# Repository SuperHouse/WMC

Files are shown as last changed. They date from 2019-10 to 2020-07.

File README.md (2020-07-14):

Wheelchair Motor Controller
===========================

Motion controller for an electric wheelchair using 24V DC motors, such
as a Permobil F5.

Controls two wheelchair motors using a RoboClaw motor driver. It also
has outputs for a solenoid braking system, and a CAN bus interface to
communicate with other modules on the chair.

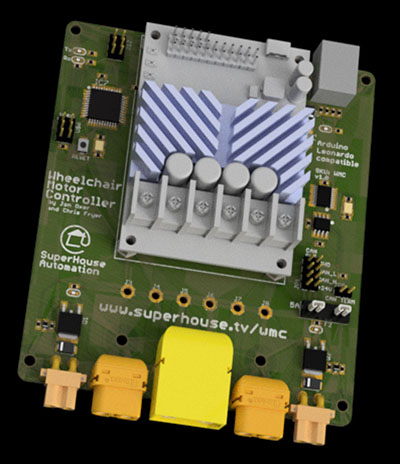
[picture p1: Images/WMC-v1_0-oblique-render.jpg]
Wheelchair Motor Controller


Features:

 * Takes power from the chair battery.
 * Mounting location for RoboClaw motor driver.
 * Communicates with RoboClaw using serial commands.
 * MOSFETs to release mechanical brakes.
 * CAN bus.

More information is available at:

  https://www.superhouse.tv/wmc

Hardware
--------
The "Hardware" directory contains the PCB design as an EAGLE project.
EAGLE PCB design software is available from Autodesk free for
non-commercial use.

Firmware
--------
The "Firmware" directory contains example firmware as an Arduino
project.

Credits
-------
 * Jonathan Oxer <jon@oxer.com.au>
 * Chris Fryer <chris.fryer78@gmail.com>

License
-------
Copyright 2019-2020 SuperHouse Automation Pty Ltd  www.superhouse.tv  

The hardware portion of this project is licensed under the TAPR Open
Hardware License (www.tapr.org/OHL). The "license" folder within this
repository contains a copy of this license in plain text format.

The software portion of this project is licensed under the Simplified
BSD License. The "licence" folder within this project contains a
copy of this license in plain text format.

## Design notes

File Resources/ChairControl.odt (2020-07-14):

Chair Controller

Modular open source electric wheelchair controller.

Different methods of control to both drive the chair and to operate an arbitrary number of and variety of actuator.

Using a button and joystick to navigate a menu to control chair functions, or having a single button for each function when user is unwilling or unable to use a menu.

The chair must be able to integrate with other accessible technologies. Such as operating as a HID device, eg. a bluetooth mouse or keyboard and connecting to an environmental control system.

EWC autopilot.

Setting up the wheelchair should be as simple and accessible as possible – not needing any special equipment to do so – while also giving advanced users advanced options including a well documented API. I’m thinking a web based interface due to the ubiquity of web browsers.

It needs to be easy to add custom modules. All hardware and software on the chair should be “off the shelf”, such as the use of CAN throughout and Arduino compatible microcontrollers. I wish it to be possible to use

Chair needs

Normal proportional joystick.

Mini Joystick.

On / Off switch.

Button.

Contact button.

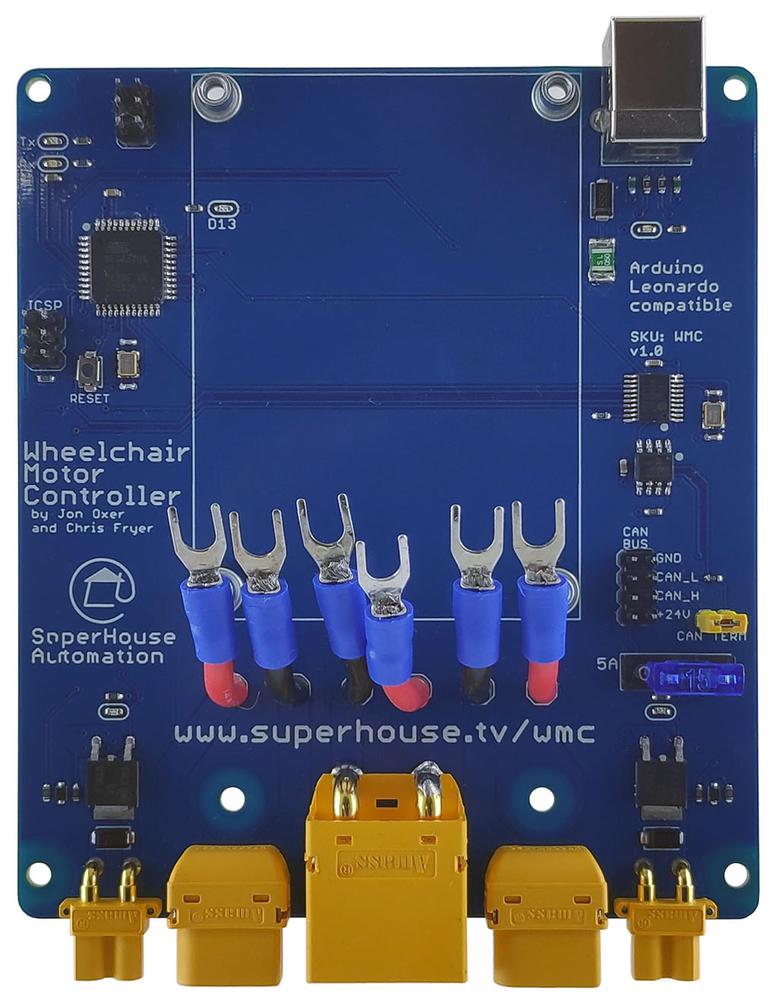
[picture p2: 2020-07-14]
Images/WMC-v1_0-top.jpg

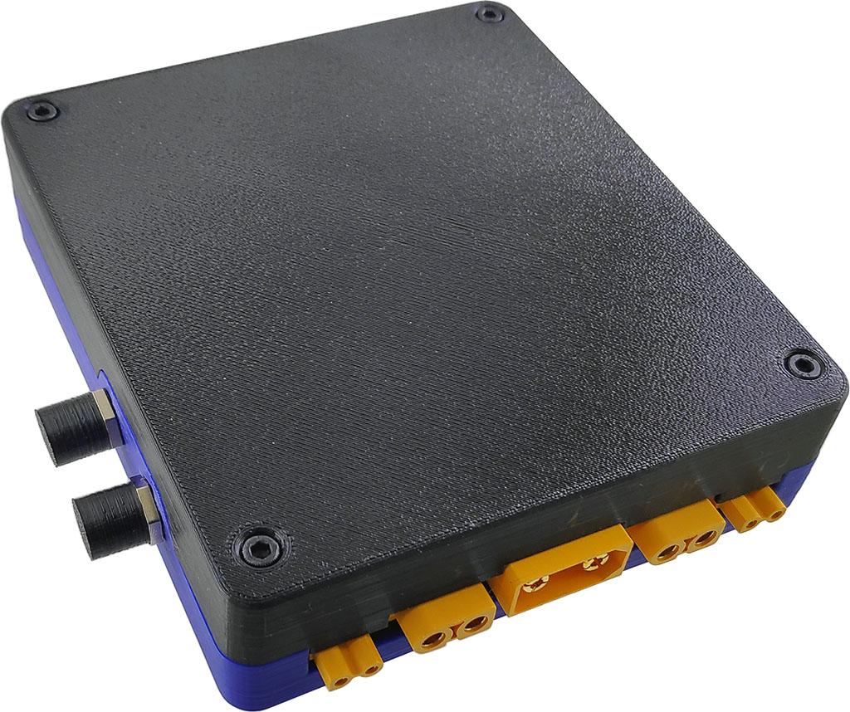
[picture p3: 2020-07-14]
Images/WMC-v1_0-case.jpg

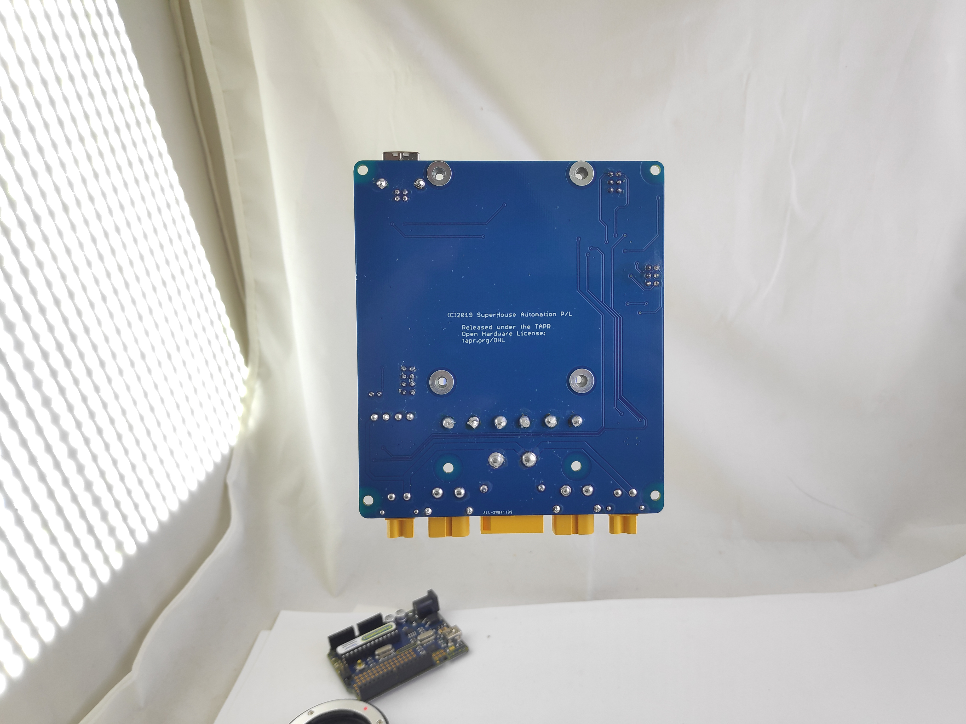
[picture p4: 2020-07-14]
Images/2019-10-31 21.18.55.jpg

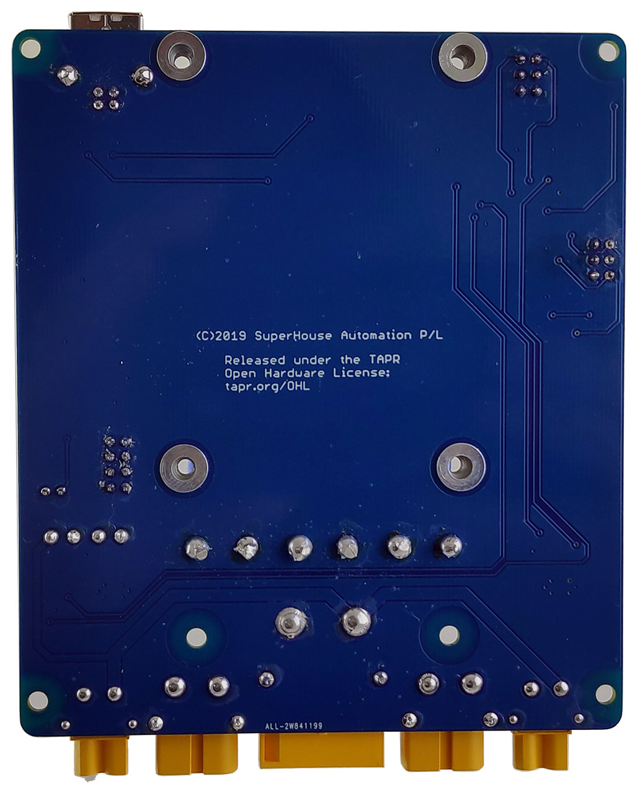
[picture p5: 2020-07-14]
Images/WMC-v1_0-bottom.jpg

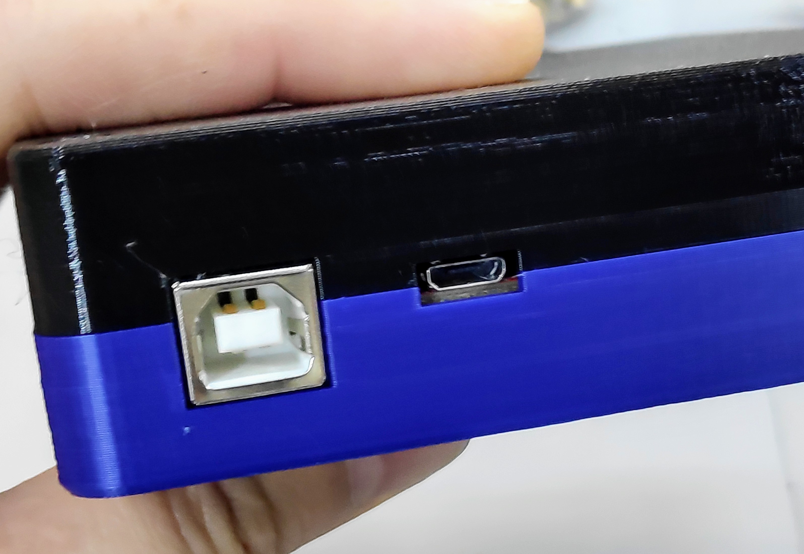
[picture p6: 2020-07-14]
Images/2019-11-03 09.05.40.jpg

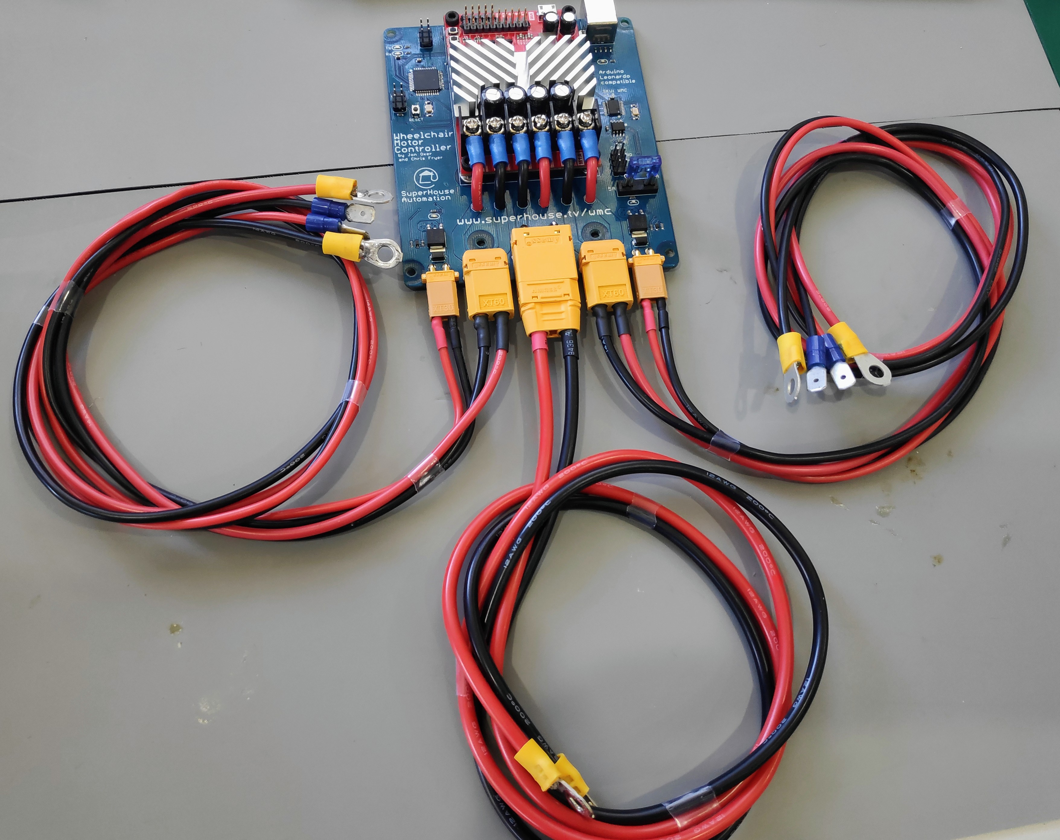
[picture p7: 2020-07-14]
Images/2019-10-29 14.47.06.jpg

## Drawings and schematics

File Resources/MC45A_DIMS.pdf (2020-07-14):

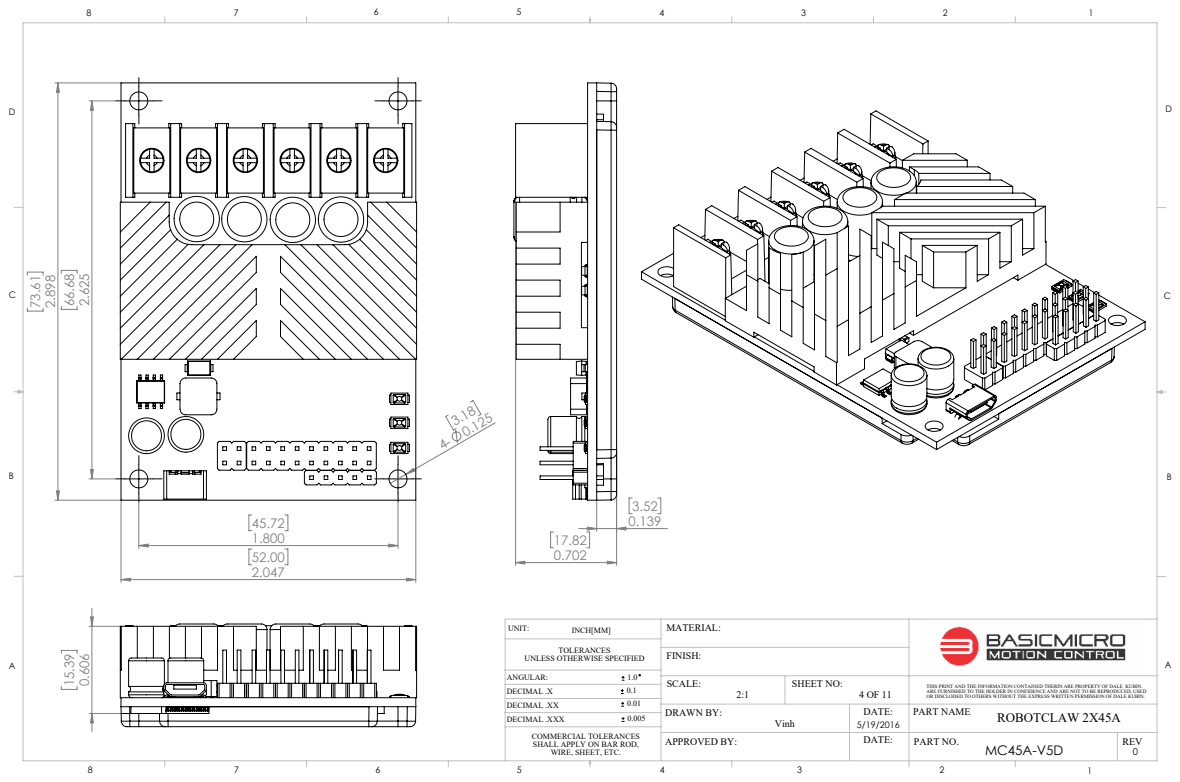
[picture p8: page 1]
PART NO.; REV; DRAWN BY:; APPROVED BY:; SCALE:; SHEET NO:; ROBOTCLAW 2X45A Vinh

UNLESS OTHERWISE SPECIFIED
ANGULAR:
DECIMAL .X
DECIMAL .XX
DECIMAL .XXX
COMMERCIAL TOLERANCES
SHALL APPLY ON BAR ROD,
WIRE, SHEET, ETC.

THIS PRINT AND THE INFORMATION CONTAINED THERIN ARE PROPERTY OF DALE KUBIN.
ARE FURNISHED TO THE HOLDER IN CONFIDENCE AND ARE NOT TO BE REPRODUCED, USED
OR DISCLODED TO OTHERS WITHOUT THE EXPRESS WRITTEN PERMISSION OF DALE KUBIN.
PART NAME

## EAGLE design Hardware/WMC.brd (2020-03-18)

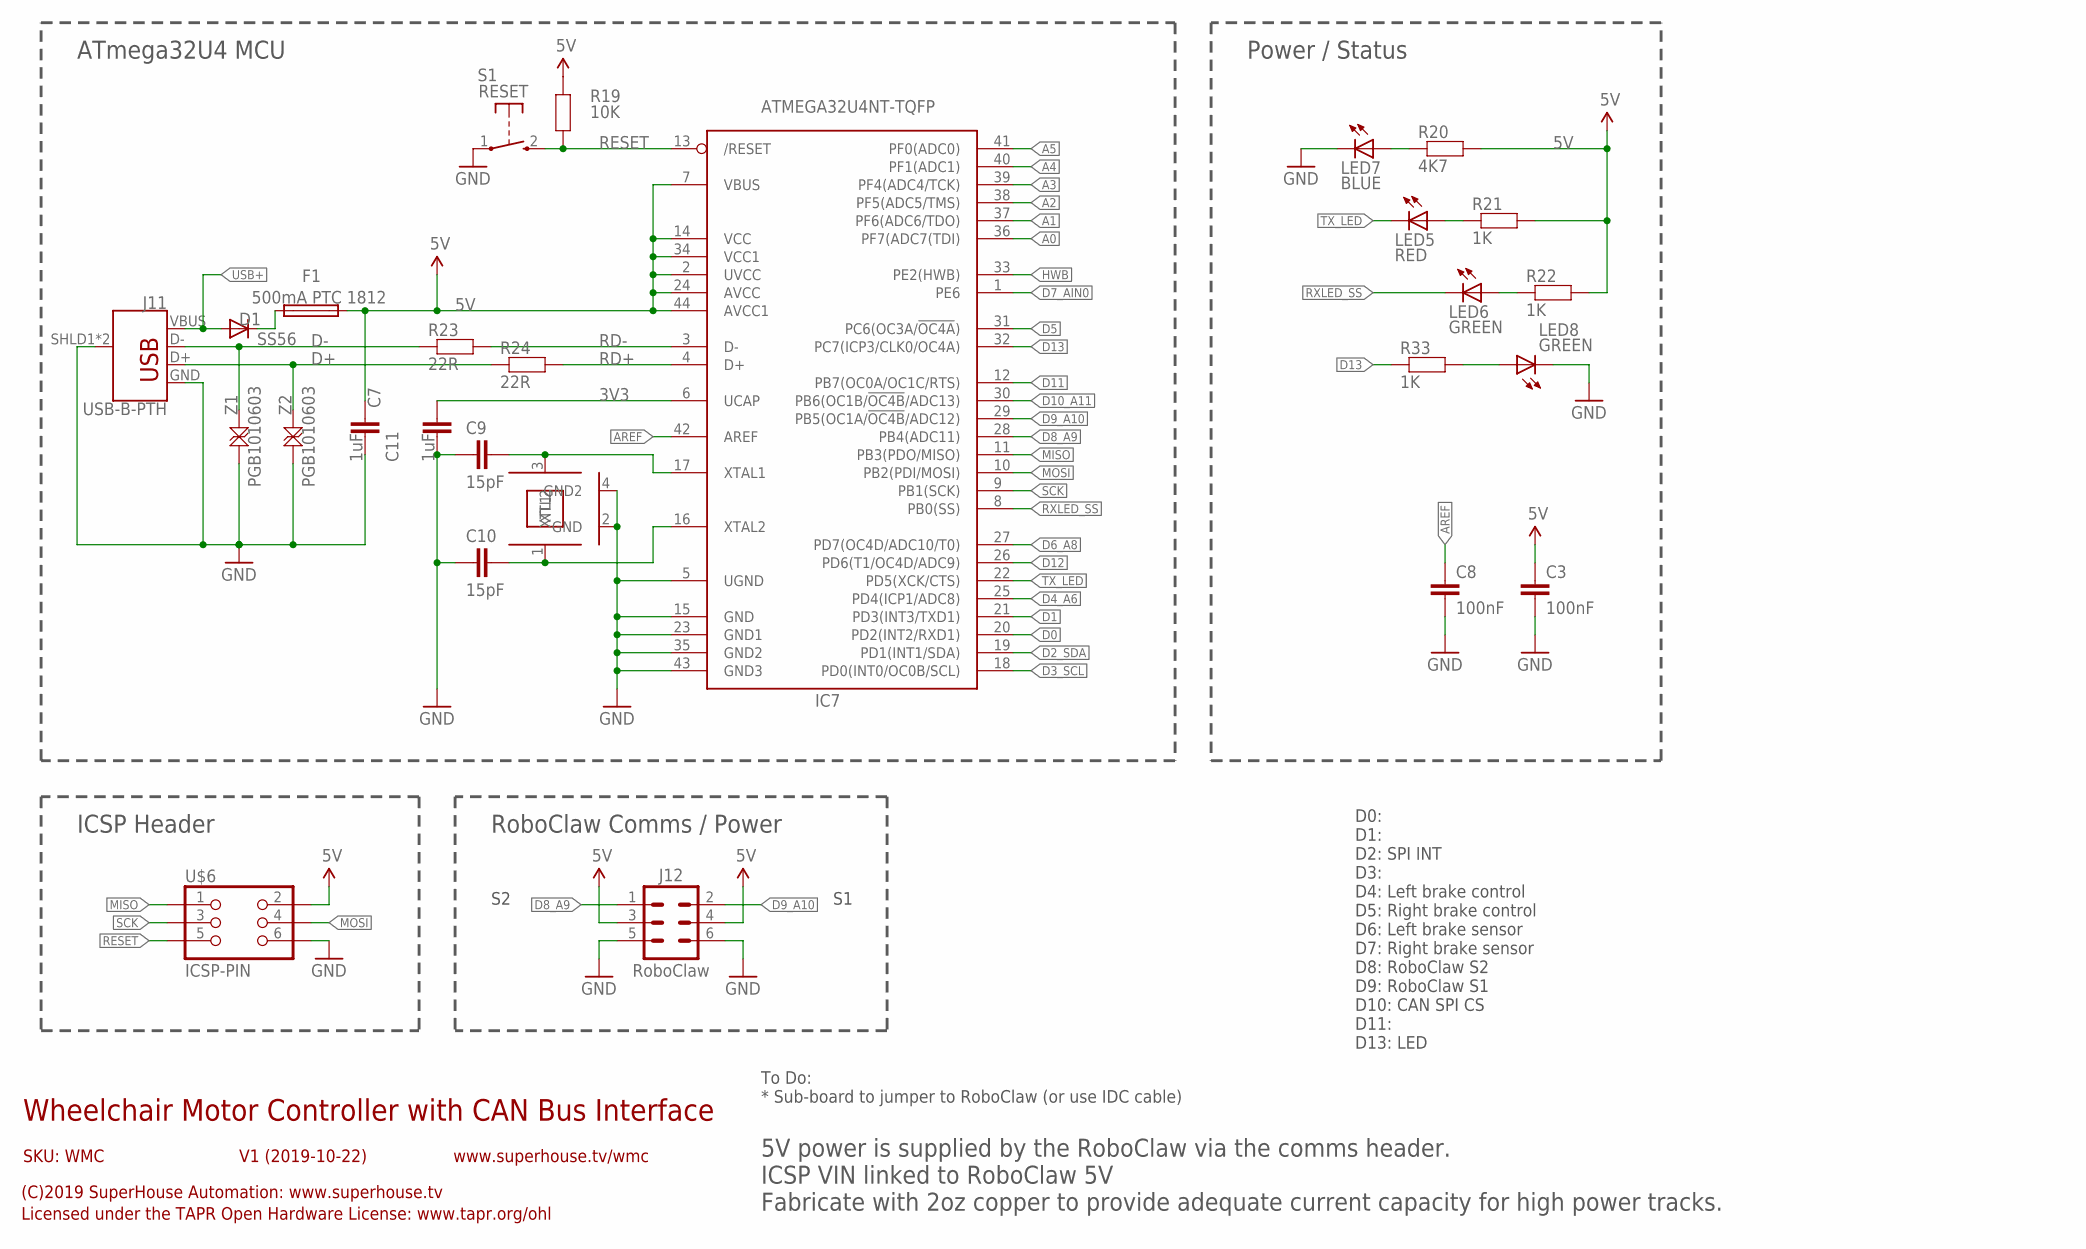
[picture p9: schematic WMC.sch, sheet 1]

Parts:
C3, C8: 100nF; C0603
C7, C11: 1uF; C0603
C9, C10: 15pF; C0603
D1: SS56; SMA-DIODE
F1: 500mA PTC 1812; 1812
IC7: ATMEGA32U4NT-TQFP; TQFP44
J11: USB-B-PTH
J12: RoboClaw; 2X03-P
LED5: RED; LED-0603
LED6, LED8: GREEN; LED-0603
LED7: BLUE; LED-0603
R19: 10K; R0603
R20: 4K7; R0603
R21, R22, R33: 1K; R0603
R23, R24: 22R; R0603
S1: RESET; TACTILE_SMT_3X4X2
U$6: ICSP-PIN; 2X03-ICSP
XTL2: 16MHz; CRYSTAL-SMD-3X2
Z1, Z2: PGB1010603; TVS0603

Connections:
3V3: C11.2, IC7.6 (UCAP)
5V: C3.1, C7.1, F1.2, IC7.2 (UVCC), IC7.7 (VBUS), IC7.14 (VCC), IC7.24 (AVCC), IC7.34 (VCC1), IC7.44 (AVCC1), J12.3, J12.4, R19.2, R20.2, R21.2, R22.2, U$6.2; also elsewhere on the board
A0: IC7.36 (PF7(ADC7(TDI))
A1: IC7.37 (PF6(ADC6/TDO))
A2: IC7.38 (PF5(ADC5/TMS))
A3: IC7.39 (PF4(ADC4/TCK))
A4: IC7.40 (PF1(ADC1))
A5: IC7.41 (PF0(ADC0))
AREF: C8.1, IC7.42 (AREF)
D0: IC7.20 (PD2(INT2/RXD1))
D1: IC7.21 (PD3(INT3/TXD1))
D2_SDA: IC7.19 (PD1(INT1/SDA)); also elsewhere on the board
D3_SCL: IC7.18 (PD0(INT0/OC0B/SCL))
D4_A6: IC7.25 (PD4(ICP1/ADC8)); also elsewhere on the board
D5: IC7.31 (PC6(OC3A/!OC4A!)); also elsewhere on the board
D6_A8: IC7.27 (PD7(OC4D/ADC10/T0)); also elsewhere on the board
D7_AIN0: IC7.1 (PE6); also elsewhere on the board
D8_A9: IC7.28 (PB4(ADC11)), J12.1
D9_A10: IC7.29 (PB5(OC1A/!OC4B!/ADC12)), J12.2
D10_A11: IC7.30 (PB6(OC1B/!OC4B!/ADC13)); also elsewhere on the board
D11: IC7.12 (PB7(OC0A/OC1C/RTS))
D12: IC7.26 (PD6(T1/OC4D/ADC9))
D13: IC7.32 (PC7(ICP3/CLK0/OC4A)), R33.1
D+: J11.D+, R24.1, Z2.2
D-: J11.D-, R23.1, Z1.2
GND: C3.2, C7.2, C8.2, C9.1, C10.1, C11.1, IC7.5 (UGND), IC7.15 (GND), IC7.23 (GND1), IC7.35 (GND2), IC7.43 (GND3), J11.GND, J11.SHLD1 (SHIELD), J11.SHLD2 (SHIELD), J12.5, J12.6, LED7.C, LED8.C, S1.1, U$6.6, XTL2.2 (GND), XTL2.4 (GND2), Z1.1, Z2.1; also elsewhere on the board
HWB: IC7.33 (PE2(HWB))
MISO: IC7.11 (PB3(PDO/MISO)), U$6.1; also elsewhere on the board
MOSI: IC7.10 (PB2(PDI/MOSI)), U$6.4; also elsewhere on the board
unnamed: C9.2, IC7.17 (XTAL1), XTL2.3 (XTL2)
unnamed: C10.2, IC7.16 (XTAL2), XTL2.1 (XTL1)
unnamed: LED7.A, R20.1
unnamed: LED5.A, R21.1
unnamed: LED6.A, R22.1
unnamed: D1.C, F1.1
unnamed: LED8.A, R33.2
RD+: IC7.4 (D+), R24.2
RD-: IC7.3 (D-), R23.2
RESET: IC7.13 (/RESET), R19.1, S1.2 (S), U$6.5
RXLED_SS: IC7.8 (PB0(SS)), LED6.C
SCK: IC7.9 (PB1(SCK)), U$6.3; also elsewhere on the board
TX_LED: IC7.22 (PD5(XCK/CTS)), LED5.C
USB+: D1.A, J11.VBUS

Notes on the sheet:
Wheelchair Motor Controller with CAN Bus Interface
V1 (2019-10-22)
SKU: WMC
(C)2019 SuperHouse Automation: www.superhouse.tv
Licensed under the TAPR Open Hardware License: www.tapr.org/ohl
www.superhouse.tv/wmc
To Do: * Sub-board to jumper to RoboClaw (or use IDC cable)
ATmega32U4 MCU
Power / Status
ICSP Header
RoboClaw Comms / Power
5V power is supplied by the RoboClaw via the comms header. ICSP VIN linked to RoboClaw 5V Fabricate with 2oz copper to provide adequate current capacity for high power tracks.
D0: D1: D2: SPI INT D3: D4: Left brake control D5: Right brake control D6: Left brake sensor D7: Right brake sensor D8: RoboClaw S2 D9: RoboClaw S1 D10: CAN SPI CS D11: D13: LED

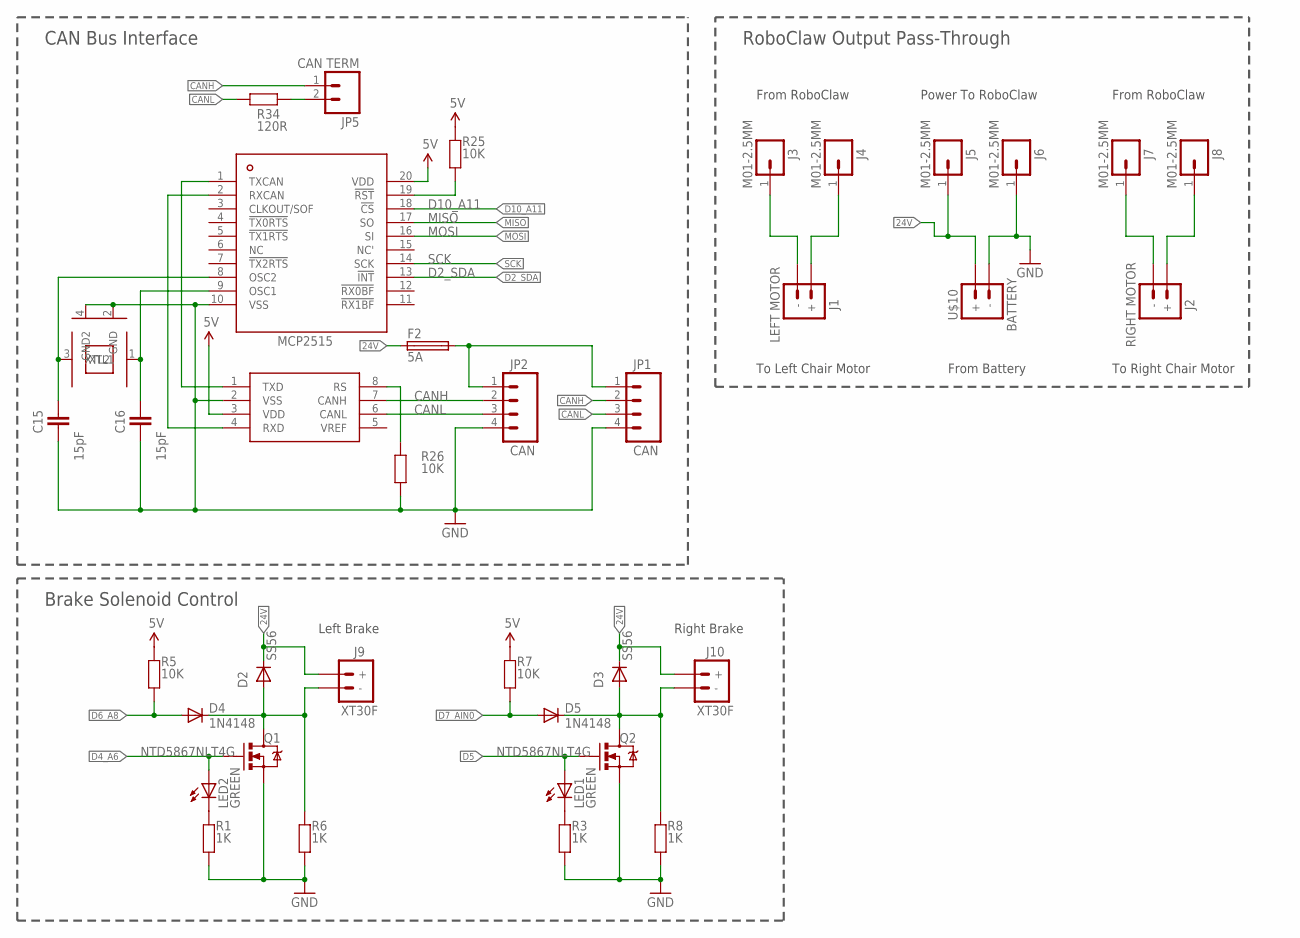
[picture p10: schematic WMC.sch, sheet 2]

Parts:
C15, C16: 15pF; C0603
D2, D3: SS56; SMA-DIODE
D4, D5: 1N4148; SOD-323
F2: 5A; MCCQ-122
IC5: MCP2551; SO08
IC6: MCP2515; TSSOP20
J1: LEFT MOTOR; XT60PW-F
J2: RIGHT MOTOR; XT60PW-F
J3, J4, J5, J6, J7, J8: M01-2.5MM; 1X01-2.5MM
J9, J10: XT30F; XT30PW-F
JP1, JP2: CAN; 1X04-P
JP5: CAN TERM; 1X02-P
LED1, LED2: GREEN; LED-0603
Q1, Q2: NTD5867NLT4G; DPACK
R1, R3, R6, R8: 1K; R0603
R5, R7, R25, R26: 10K; R0603
R34: 120R; R0603
U$10: BATTERY; XT90PW-M
XTL4: 16MHz; CRYSTAL-SMD-3X2

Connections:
5V: IC5.3 (VDD), IC6.20 (VDD), R5.2, R7.2, R25.2; also elsewhere on the board
24V: D2.C, D3.C, F2.1, F2.2 (1), J5.1, J9.+, J10.+, U$10.+
CANH: IC5.7 (CANH), JP1.2, JP2.2, JP5.1
CANL: IC5.6 (CANL), JP1.3, JP2.3, R34.1
D2_SDA: IC6.13 (!INT); also elsewhere on the board
D4_A6: LED2.A, Q1.1 (G); also elsewhere on the board
D5: LED1.A, Q2.1 (G); also elsewhere on the board
D6_A8: D4.2 (A), R5.1; also elsewhere on the board
D7_AIN0: D5.2 (A), R7.1; also elsewhere on the board
D10_A11: IC6.18 (!CS); also elsewhere on the board
GND: C15.1, C16.1, IC5.2 (VSS), IC6.10 (VSS), J6.1, JP1.4, JP2.4, Q1.3 (S), Q2.3 (S), R1.1, R3.1, R6.1, R8.1, R26.1, U$10.-, XTL4.2 (GND), XTL4.4 (GND2); also elsewhere on the board
LEFT_BRAKE: D2.A, D4.1 (C), J9.-, Q1.2 (D), R6.2
MISO: IC6.17 (SO); also elsewhere on the board
MOSI: IC6.16 (SI); also elsewhere on the board
unnamed: LED2.C, R1.2
unnamed: F2.3 (2), F2.4 (2), JP1.1, JP2.1
unnamed: J1.+, J4.1
unnamed: LED1.C, R3.2
unnamed: J1.-, J3.1
unnamed: J2.-, J7.1
unnamed: J2.+, J8.1
unnamed: IC6.19 (!RST), R25.1
unnamed: IC5.1 (TXD), IC6.1 (TXCAN)
unnamed: IC5.4 (RXD), IC6.2 (RXCAN)
unnamed: IC5.8 (RS), R26.2
unnamed: C15.2, IC6.8 (OSC2), XTL4.3 (XTL2)
unnamed: C16.2, IC6.9 (OSC1), XTL4.1 (XTL1)
unnamed: JP5.2, R34.2
RIGHT_BRAKE: D3.A, D5.1 (C), J10.-, Q2.2 (D), R8.2
SCK: IC6.14 (SCK); also elsewhere on the board

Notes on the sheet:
RoboClaw Output Pass-Through
CAN Bus Interface
Brake Solenoid Control
Left Brake
Right Brake
From RoboClaw
From Battery
To Right Chair Motor
To Left Chair Motor
Power To RoboClaw

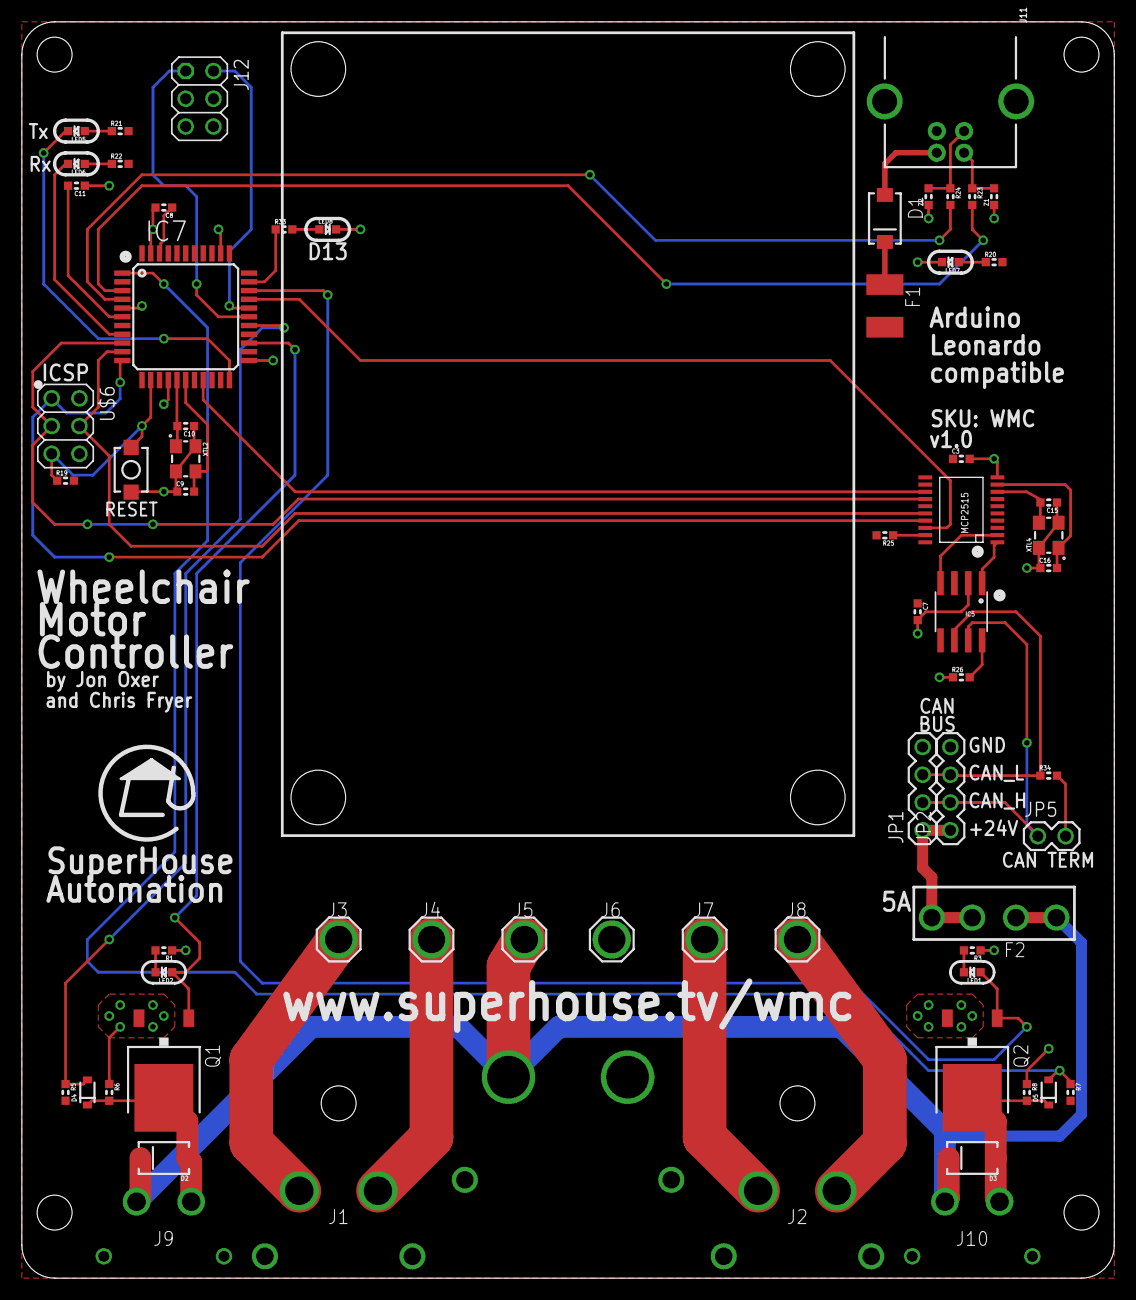
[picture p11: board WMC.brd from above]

Board: 2 copper layers, 100.0 x 115.0 mm, 64 parts (0 on the bottom side), 50 nets.

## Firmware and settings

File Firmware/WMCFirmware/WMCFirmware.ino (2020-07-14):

/**
   Receives messages via CAN bus and controls a RoboClaw motor driver module.

   Intended for testing of wheelchair control using a RoboClaw motor controller,
   with commands received over CAN bus from a Chair Breakout Mini attached to
   a wheelchair joystick.

   CAN message format is currently very simplistic, and doesn't adhere to CANopen
   or any other sensible convention. It uses packet IDs to designate the axis:

    Packet ID 0x12 = X axis
    Packet ID 0x13 = Y axis

   The message value signifies the position, from 0 to 127, with 64 as the mid
   point. So a centered joystick would have:

     Packet ID: 0x12. Value: 64
     Packet ID: 0x13. Value: 64

    Joystick full forward would have:

     Packet ID: 0x12. Value: 64
     Packet ID: 0x13. Value: 127

   By Chris Fryer (chris.fryer78@gmail.com) and Jonathan Oxer (jon@oxer.com.au)
   www.superhouse.tv

   To do:
   - Activate brakes when speed reaches 0. This needs to be checked with the RoboClaw,
   because the chair may take a while to stop after it has been set to 0 speed.
*/


// Configuration should be done in the included file:
#include "config.h"

#include <CAN.h>             // CAN bus communication: https://github.com/sandeepmistry/arduino-CAN (available in library manager)
#include <SoftwareSerial.h>  // Required for RoboClaw serial connection
#include "RoboClaw.h"        // Library from BasicMicro

// Serial link to RoboClaw
SoftwareSerial serial(RC_S1, RC_S2);
RoboClaw roboclaw(&serial, 10000);

String SerialBuffer = ""; // Buffer for incoming serial messages from console

// The "...InputValue" variables are taken from inputs and mixed or used directly
int XInputValue = MID_OUTPUT_VALUE; // Start at the mid-point
int YInputValue = MID_OUTPUT_VALUE; // Start at the mid-point

// The "...MotorSetpoint" variables are the target speed we want to reach
double LeftMotorSetpoint  = MID_OUTPUT_VALUE; // Start at the mid-point
double RightMotorSetpoint = MID_OUTPUT_VALUE; // Start at the mid-point

// The "...MotorCurrentValue" variables are directly used to drive the motors
double LeftMotorCurrentValue  = MID_OUTPUT_VALUE;
double RightMotorCurrentValue = MID_OUTPUT_VALUE;

// Recalculate the motor speed based on current and target
long last_calculation_time = 0;
unsigned int motor_output_calculation_interval = 100; // How often to update the motor speed
int speed_output_acceleration_increment = 2; // How big the jump should be per interval
int speed_output_deceleration_increment = 5; // How big the jump should be per interval

// Check whether we need to apply the brakes
long last_brake_check_time = 0;
unsigned int brake_check_interval = 500;

// Serial port reports
long last_serial_report_time = 0;
unsigned int serial_report_interval = 200;

// CAN bus reports
long last_can_report_time = 0;
unsigned int can_report_interval = 500;

char can_msg[8];                   // Buffer for outgoing CAN messages
char incoming_message_buffer[12];  // Buffer for incoming CAN messages

// Check temperature of RoboClaw motor driver
float roboclaw_temperature              = 0.0;
long last_temperature_check_time        = 0;
unsigned int temperature_check_interval = 1000;
float roboclaw_voltage                  = 0.0;
float roboclaw_left_current             = 0.0;
float roboclaw_right_current            = 0.0;

/*
   Setup
*/
void setup() {
  Serial.begin(115200);     // Console
  //while (!Serial) {
  //  ; // wait for serial port to connect. Needed for native USB port only
  //}

  Serial.println("RoboClaw CAN bus interface v1.2");

  Serial.print("Opening serial comms to RoboClaw: ");
  roboclaw.begin(38400);  // RoboClaw packet serial connection
  char version[32];
  if (roboclaw.ReadVersion(ADDRESS, version)) {
    Serial.print(version);
    Serial.println(" done");
  } else {
    Serial.println(" FAILED");
  }

  Serial.print("Setting brake control outputs and sensors: ");
  pinMode(LEFT_BRAKE_CONTROL_PIN,  OUTPUT);
  pinMode(RIGHT_BRAKE_CONTROL_PIN, OUTPUT);
  pinMode(LEFT_BRAKE_SENSOR_PIN,   INPUT);
  pinMode(RIGHT_BRAKE_SENSOR_PIN,  INPUT);
  digitalWrite(LEFT_BRAKE_CONTROL_PIN,  LOW);
  digitalWrite(RIGHT_BRAKE_CONTROL_PIN, LOW);
  Serial.println("done");

  //Set PID Coefficients
  roboclaw.SetM1VelocityPID(ADDRESS, KD, KP, KI, QPPS); // Right motor
  roboclaw.SetM2VelocityPID(ADDRESS, KD, KP, KI, QPPS); // Left motor

  Serial.println("Starting CAN Receiver");
  // start the CAN bus at 500 kbps
  if (!CAN.begin(500E3)) {
    Serial.println("Starting CAN failed!");
    //while (1);
  } else {
    Serial.println("Started CAN OK");
  }

  // register the receive callback
  CAN.onReceive(onReceive);

  delay(100);
}

/**
   Loop
*/
void loop() {
  long current_time = millis(); // Used by various timed events in the loop

  /**
     Motor speed updates can be managed in this sketch, or they can be
     delegated to the RoboClaw if the PID values are set correctly. The
     first option below applies acceleration control within the sketch,
     while the second attempts to drive the motors immediately to their
     target speed and relies on the RoboClaw to take care of smoothing.
  */
  // OPTION 1: Manage acceleration within the sketch.

  // Update the desired motor setting periodically
  if (current_time > (last_calculation_time + motor_output_calculation_interval))
  {
    // WARNING: the calculations below don't yet account for overshoot, so
    // the increment could take it past the target

    /* Motor moving forwards (Speed greater than 64) */
    if (LeftMotorCurrentValue >= 64) // We're moving forwards
    {      
      if (LeftMotorCurrentValue < LeftMotorSetpoint) // Accelerating forwards
      {
        if((LeftMotorSetpoint - LeftMotorCurrentValue) < speed_output_deceleration_increment) // If we're closer than the increment
        {
          LeftMotorCurrentValue = LeftMotorSetpoint;
        } else {
          LeftMotorCurrentValue += speed_output_acceleration_increment;
        }
      }
      if (LeftMotorCurrentValue > LeftMotorSetpoint) // Decelerating forwards
      {
        if((LeftMotorCurrentValue - LeftMotorSetpoint) < speed_output_deceleration_increment) // If we're closer than the increment
        {
          LeftMotorCurrentValue = LeftMotorSetpoint;
        } else {
          LeftMotorCurrentValue -= speed_output_deceleration_increment;
        }
      }
    }

    if (RightMotorCurrentValue >= 64) // We're moving forwards
    {      
      if (RightMotorCurrentValue < RightMotorSetpoint) // Accelerating forwards
      {
        if((RightMotorSetpoint - RightMotorCurrentValue) < speed_output_deceleration_increment) // If we're closer than the increment
        {
          RightMotorCurrentValue = RightMotorSetpoint;
        } else {
          RightMotorCurrentValue += speed_output_acceleration_increment;
        }
      }
      if (RightMotorCurrentValue > RightMotorSetpoint) // Decelerating forwards
      {
        if((RightMotorCurrentValue - RightMotorSetpoint) < speed_output_deceleration_increment) // If we're closer than the increment
        {
          RightMotorCurrentValue = RightMotorSetpoint;
        } else {
          RightMotorCurrentValue -= speed_output_deceleration_increment;
        }
      }
    }

    /* Motor moving backwards (Speed less than 64) */
    if (LeftMotorCurrentValue < 64) // We're moving backwards
    {      
      if (LeftMotorCurrentValue > LeftMotorSetpoint) // Accelerating backwards
      {
        if((LeftMotorCurrentValue - LeftMotorSetpoint) < speed_output_deceleration_increment) // If we're closer than the increment
        {
          LeftMotorCurrentValue = LeftMotorSetpoint;
        } else {
          LeftMotorCurrentValue -= speed_output_acceleration_increment;
        }
      }
      if (LeftMotorCurrentValue < LeftMotorSetpoint) // Decelerating backwards
      {
        if((LeftMotorSetpoint - LeftMotorCurrentValue) < speed_output_deceleration_increment) // If we're closer than the increment
        {
          LeftMotorCurrentValue = LeftMotorSetpoint;
        } else {
          LeftMotorCurrentValue += speed_output_deceleration_increment;
        }
      }
    }

    if (RightMotorCurrentValue < 64) // We're moving backwards
    {      
      if (RightMotorCurrentValue > RightMotorSetpoint) // Accelerating backwards
      {
        if((RightMotorCurrentValue - RightMotorSetpoint) < speed_output_deceleration_increment) // If we're closer than the increment
        {
          RightMotorCurrentValue = RightMotorSetpoint;
        } else {
          RightMotorCurrentValue -= speed_output_acceleration_increment;
        }
      }
      if (RightMotorCurrentValue < RightMotorSetpoint) // Decelerating backwards
      {
        if((RightMotorSetpoint - RightMotorCurrentValue) < speed_output_deceleration_increment) // If we're closer than the increment
        {
          RightMotorCurrentValue = RightMotorSetpoint;
        } else {
          RightMotorCurrentValue += speed_output_deceleration_increment;
        }
      }
    }

    last_calculation_time = current_time;
  }


  // Option 2: Allow RoboClaw to control motor response.
  //LeftMotorCurrentValue = LeftMotorSetpoint;
  //RightMotorCurrentValue = RightMotorSetpoint;


  // See if either wheel is stationary, and apply the brake if it is
  if (current_time > (last_brake_check_time + brake_check_interval))
  {
    //long LeftMotorSpeed  = roboclaw.ReadSpeedM2(ADDRESS);
    //if(LeftMotorSpeed == 0)
    if (LeftMotorCurrentValue >= (MID_OUTPUT_VALUE - DEAD_SPOT_WIDTH) && LeftMotorCurrentValue <= (MID_OUTPUT_VALUE + DEAD_SPOT_WIDTH))
    {
      digitalWrite(LEFT_BRAKE_CONTROL_PIN, LOW);
      //Serial.println("Left brake applied");
    }
    //long RightMotorSpeed = roboclaw.ReadSpeedM1(ADDRESS);
    //if(RightMotorSpeed == 0)
    if (RightMotorCurrentValue >= (MID_OUTPUT_VALUE - DEAD_SPOT_WIDTH) && RightMotorCurrentValue <= (MID_OUTPUT_VALUE + DEAD_SPOT_WIDTH))
    {
      digitalWrite(RIGHT_BRAKE_CONTROL_PIN, LOW);
      //Serial.println("Right brake applied");
    }
    last_brake_check_time = current_time;
  }
  // Release the brake if speed is set to anything except 0
  if (LeftMotorCurrentValue < (MID_OUTPUT_VALUE - DEAD_SPOT_WIDTH) || LeftMotorCurrentValue > (MID_OUTPUT_VALUE + DEAD_SPOT_WIDTH))
  {
    digitalWrite(LEFT_BRAKE_CONTROL_PIN, HIGH);
    //Serial.println("Left brake released");
  }
  if (RightMotorCurrentValue < (MID_OUTPUT_VALUE - DEAD_SPOT_WIDTH) || RightMotorCurrentValue > (MID_OUTPUT_VALUE + DEAD_SPOT_WIDTH))
  {
    digitalWrite(RIGHT_BRAKE_CONTROL_PIN, HIGH);
    //Serial.println("Right brake released");
  }

  // Set the motors to their currently configured speeds.
  // The strange calculation below is to "rotate" the value around 64, which is the mid-point.
  // First the value is offset down by 127 (eg: value 100 -> -27, 17 -> -110) then it's
  // made positive again. This has the effect that offsets above 64 become offsets below 64,
  // and vice versa.
  roboclaw.ForwardBackwardM2(ADDRESS, (LeftMotorCurrentValue - 127) * -1);
  roboclaw.ForwardBackwardM1(ADDRESS, (RightMotorCurrentValue - 127) * -1);

  if (OUTPUT_DEBUG)
  {
    if (current_time > (last_serial_report_time + serial_report_interval))
    {
      //long LeftMotorSpeedReport  = roboclaw.ReadSpeedM2(ADDRESS);
      //long RightMotorSpeedReport = roboclaw.ReadSpeedM1(ADDRESS);

      Serial.print("Ls:");
      Serial.print(LeftMotorSetpoint);
      Serial.print(" La:");
      Serial.print(LeftMotorCurrentValue);
      //Serial.print(" Lr:");
      //Serial.print(LeftMotorSpeedReport);


      Serial.print(" Rs:");
      Serial.print(RightMotorSetpoint);
      Serial.print(" Ra:");
      Serial.print(RightMotorCurrentValue);
      //Serial.print(" Rr:");
      //Serial.print(RightMotorSpeedReport);

      Serial.print(" Dsp:");
      Serial.print(LeftMotorSetpoint - RightMotorSetpoint);
      Serial.print(" Dcv:");
      Serial.print(LeftMotorCurrentValue - RightMotorCurrentValue);
      //Serial.print(" ");
      
      Serial.print(" V:");
      Serial.print(roboclaw_voltage);
      //Serial.print("");
      Serial.print(" T:");
      Serial.print(roboclaw_temperature);
      //Serial.print("|");
      Serial.print(" Il:");
      Serial.print(roboclaw_left_current);
      //Serial.print("|");
      Serial.print(" Ir:");
      Serial.print(roboclaw_right_current);
      Serial.println("");
      
      Serial.println();
      last_serial_report_time = current_time;
    }
  }

  if (CAN_STATUS_REPORTS)
  {
    if (current_time > (last_can_report_time + can_report_interval))
    {
      long LeftMotorSpeedReport  = roboclaw.ReadSpeedM2(ADDRESS);
      long RightMotorSpeedReport = roboclaw.ReadSpeedM1(ADDRESS);

      Serial.println("Reporting to CAN");
      Serial.print("Raw: ");
      Serial.println(roboclaw_temperature);
      dtostrf(roboclaw_temperature, 7, 2, can_msg);
      Serial.print("Raw2: ");
      Serial.println(can_msg);
      sprintf(can_msg, "%f", roboclaw_temperature);
      Serial.print("CAN: ");
      CAN.beginPacket(0x14);      // Packet ID 0x14 for temperature
      for (int i = 0; i < 7; i++) // Hard coded length. Make variable?
      {
        Serial.print((char)can_msg[i]);
        CAN.write(can_msg[i]);
      }
      CAN.endPacket();
      Serial.println();

      sprintf(can_msg, "%d", roboclaw_left_current);
      CAN.beginPacket(0x15);      // Packet ID 0x15 for left_current
      for (int i = 0; i < 8; i++) // Hard coded length. Make variable?
      {
        CAN.write(can_msg[i]);
      }
      CAN.endPacket();

      sprintf(can_msg, "%d", roboclaw_right_current);
      CAN.beginPacket(0x16);      // Packet ID 0x16 for right_current
      for (int i = 0; i < 12; i++) // Hard coded length. Make variable?
      {
        CAN.write(can_msg[i]);
      }
      CAN.endPacket();

      /*
        Serial.print("Left:");
        Serial.print(LeftMotorSetpoint);
        Serial.print("|");
        Serial.print(LeftMotorCurrentValue);
        Serial.print("|");
        Serial.print(LeftMotorSpeedReport);

        Serial.print("   Right:");
        Serial.print(RightMotorSetpoint);
        Serial.print("|");
        Serial.print(RightMotorCurrentValue);
        Serial.print("|");
        Serial.print(RightMotorSpeedReport);

        Serial.print("   Delta:");
        Serial.print(LeftMotorSetpoint - RightMotorSetpoint);
        Serial.print("|");
        Serial.print(LeftMotorCurrentValue - RightMotorCurrentValue);
        Serial.print(" | ");
        Serial.print("V:");
        Serial.print(roboclaw_voltage);
        Serial.print(" | ");
        Serial.print("T:");
        Serial.print(roboclaw_temperature);
        Serial.print("|");
        Serial.print("L:");
        Serial.print(roboclaw_left_current);
        Serial.print("|");
        Serial.print("R:");
        Serial.print(roboclaw_right_current);
        Serial.println("|");
      */

      last_can_report_time = current_time;
    }
  }

  processSerialCommands();

  if (current_time > (last_temperature_check_time + temperature_check_interval))
  {
    last_temperature_check_time = current_time;
    read_roboclaw_temperature();
    read_roboclaw_voltage();
    read_roboclaw_current();
  }



  // WARNING: only one of these below should be uncommented
  //splitInputChannels(); // Apply X axis to left motor, Y axist to right motor
  mixInputChannels();  // Merge X and Y axis to derive a speed and direction
}

/**
   Check the serial buffer for any messages. The format is a pair of numbers
   that represent the X and Y joystick positions, with "90" as the mid point:
   "90,90" is joystick centered.
   "80,90" is joystick slightly left.
   "100,90" is joystick slightly right.
   "100,120" is joystick slightly right and forward.
*/
void processSerialCommands()
{
  /*
    while (Serial.available() > 0) {
    int inChar = Serial.read();
    if (isDigit(inChar)) {
      // Convert the incoming byte to a char and add it to the string:
      SerialBuffer += (char)inChar;
    }
    if (inChar == '\n') {
      int InputValue = SerialBuffer.toInt();
      if((InputValue >= MIN_OUTPUT_VALUE) && (InputValue <= MAX_OUTPUT_VALUE))
      {
        XInputValue = InputValue;
        YInputValue = InputValue;
        Serial.print("Setting speed: ");
        Serial.println(InputValue, DEC);
      }

      // clear the string for new input:
      SerialBuffer = "";
    }
    }
  */

  while (Serial.available() > 0) {
    String XInputString  = Serial.readStringUntil(',');
    //Serial.read(); //next character is comma, so skip it using this
    String YInputString = Serial.readStringUntil('\n');
    int XInputRaw = XInputString.toInt();
    int YInputRaw = YInputString.toInt();
    if (  XInputRaw >= MIN_OUTPUT_VALUE
          && XInputRaw <= MAX_OUTPUT_VALUE
          && YInputRaw >= MIN_OUTPUT_VALUE
          && YInputRaw <= MAX_OUTPUT_VALUE )
    {
      XInputValue = XInputRaw;
      YInputValue = YInputRaw;
    }
  }
}

/**
   Treat X and Y input values as separate, and send them to the motors individually
*/
void splitInputChannels()
{
  LeftMotorSetpoint  = XInputValue;
  RightMotorSetpoint = YInputValue;
}

/**
   Mix the X and Y input values together to calculate a vector, and drive the
   motors to match that vector
*/
void mixInputChannels()
{
  int Speed    = MID_OUTPUT_VALUE;  // Forward / reverse speed of the chair
  int TurnRate = MID_OUTPUT_VALUE;  // Lower values turn left, higher turn right

  /*
     NOTE: Scaling the turn rate below is critical to making the chair behave in
     an intuitive way. If this is not scaled, the turn rate can cancel out the speed
     of the chair and make it work in a surprising way. For example, without turn
     rate scaling, if the joystick is moved diagonally to the front right (such as
     position 100,100) the chair won't move forward at all, it will turn on the spot
     with the right motor stopped and left motor at speed 100.
  */
  Speed = YInputValue - MID_OUTPUT_VALUE;
  TurnRate = (XInputValue - MID_OUTPUT_VALUE) / 4;

  // Determine left and right motor values
  int left_speed  = Speed + TurnRate;
  //int left_magnitude = abs(left_speed);
  int right_speed = Speed - TurnRate;
  //int right_magnitude = abs(right_speed);

  LeftMotorSetpoint  = left_speed  + MID_OUTPUT_VALUE;
  RightMotorSetpoint = right_speed + MID_OUTPUT_VALUE;
}


/**
   Callback when a CAN packet arrives
*/
void onReceive(int packetSize) {
  // received a packet
  int integerValue = 0;    // throw away previous integerValue
  char incomingByte;
  byte is_negative = 0;
  int bytes_received = 0;
  while (CAN.available()) {
    //Serial.print((char)CAN.read());
    incomingByte = (char)CAN.read();
    incoming_message_buffer[bytes_received] = incomingByte;
    bytes_received++;
    integerValue *= 10;  // shift left 1 decimal place
    // convert ASCII to integer, add, and shift left 1 decimal place
    integerValue = ((incomingByte - 48) + integerValue);
  }

  int axis_output = 0;
  // Only print packet data for non-RTR packets
  if (CAN.packetId() == 0x12) // Packet ID 0x12 for X axis
  {
    integerValue = incoming_message_buffer[0];

    if (CAN_DEBUG)
    {
      Serial.print("X=");
      Serial.println(integerValue, DEC);
    }

    // The values we receive are between 0 (full reverse) and 127 (full forward)
    // with 64 as the stop value. We need to convert that into a range that goes from
    // full reverse to full forward on a range to suit the motor controller. For
    // the roboclaw this is also 0 - 127, so we don't strictly need to do any
    // mapping, but this is left here so that we can scale down the motor speed
    // range to give more gentle response.

    axis_output = map(integerValue, 0, 127, MIN_OUTPUT_VALUE, MAX_OUTPUT_VALUE);
    XInputValue = constrain(axis_output, MIN_OUTPUT_VALUE, MAX_OUTPUT_VALUE);

    // This block applies a dead spot around the "stop" middle value, but instead
    // of just blocking out a small range of values, it offsets the outputted value
    // by the size of the dead spot. This is so that when the input just moves past
    // the dead spot, the value doesn't jump straight to a high value. It begins
    // with the slowest possible speed just at the edge of the dead spot and goes
    // up linearly from there. The same thing is done further down for the Y value.
    if (XInputValue <= MID_OUTPUT_VALUE - DEAD_SPOT_WIDTH)
    {
      XInputValue = XInputValue + DEAD_SPOT_WIDTH;
    } else if (XInputValue >= MID_OUTPUT_VALUE + DEAD_SPOT_WIDTH)
    {
      XInputValue = XInputValue - DEAD_SPOT_WIDTH;
    } else {
      XInputValue = MID_OUTPUT_VALUE;
    }
  }
  if (CAN.packetId() == 0x13) // Packet ID 0x13 for Y axis
  {
    integerValue = incoming_message_buffer[0];

    if (CAN_DEBUG)
    {
      Serial.print("Y=");
      Serial.println(integerValue, DEC);
    }
    axis_output = map(integerValue, 0, 127, MIN_OUTPUT_VALUE, MAX_OUTPUT_VALUE);
    YInputValue = constrain(axis_output, MIN_OUTPUT_VALUE, MAX_OUTPUT_VALUE);
    if (YInputValue <= MID_OUTPUT_VALUE - DEAD_SPOT_WIDTH)
    {
      YInputValue = YInputValue + DEAD_SPOT_WIDTH;
    } else if (YInputValue >= MID_OUTPUT_VALUE + DEAD_SPOT_WIDTH)
    {
      YInputValue = YInputValue - DEAD_SPOT_WIDTH;
    } else {
      YInputValue = MID_OUTPUT_VALUE;
    }
  }
}

void read_roboclaw_temperature()
{
  uint16_t temp = 0;
  roboclaw.ReadTemp(ADDRESS, temp);
  roboclaw_temperature = temp / 10.0;
}

void read_roboclaw_voltage()
{
  uint8_t temp = 0.0;
  temp = roboclaw.ReadMainBatteryVoltage(ADDRESS);
  roboclaw_voltage = temp / 10.0;
}

void read_roboclaw_current()
{
  int16_t temp_left = 0;
  int16_t temp_right = 0;

  roboclaw.ReadCurrents(ADDRESS, temp_right, temp_left);
  roboclaw_left_current = temp_left / 100.0;
  roboclaw_right_current = temp_right / 100.0;
}

//ReadCurrents(uint8_t address, int16_t &current1, int16_t &current2);

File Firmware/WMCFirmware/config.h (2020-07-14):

// Debug options
#define CAN_DEBUG false
#define CAN_STATUS_REPORTS false
#define OUTPUT_DEBUG true

// Don't output more than this using PWM. Scale to make this 100% output
// ludicrous mode!!
// RoboClaw speed range is 0-127, with 64 as the mid-point (stop). Lower
// numbers are reverse, higher numbers are forward.
#define MAX_OUTPUT_VALUE 127
#define MID_OUTPUT_VALUE 64
#define MIN_OUTPUT_VALUE 0

#define DEAD_SPOT_WIDTH  4

// Pin assignments
//#define LEFT_MOTOR_PIN  9
//#define RIGHT_MOTOR_PIN 6
#define RC_S1    8
#define RC_S2    9

#define LEFT_BRAKE_CONTROL_PIN   4
#define RIGHT_BRAKE_CONTROL_PIN  5
#define LEFT_BRAKE_SENSOR_PIN    6
#define RIGHT_BRAKE_SENSOR_PIN   7

// RoboClaw Config
#define ADDRESS 0x80

//Velocity PID coefficients.
#define KP 1.0     // 1.0
#define KI 0.5     // 0.5
#define KD 0.25    // 0.25
#define QPPS 44000

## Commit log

2018-08-20 Imported files from CBMINI project to begin conversion
    [CANFLYSKY.brd, CANFLYSKY.sch]
2018-08-20 Removed unnecessary parts
    [CANFLYSKY.brd, CANFLYSKY.sch]
2018-10-25 Completed initial routing
    [CANFLYSKY.brd, CANFLYSKY.sch]
2018-10-26 Finished routing
    [CANFLYSKY.brd, CANFLYSKY.sch]
2018-10-26 Updated README and renamed project files
    [FSI6CAN.brd, FSI6CAN.sch]
2018-11-24 Improved designators
    [FSI6CAN.brd, FSI6CAN.sch]
2019-04-23 Changed I/O pin for output Y2 and switch ICSP to other SPI port
    [FSI6CAN.brd, FSI6CAN.sch]
2019-04-25 Added CAN termination
    [FSI6CAN.brd, FSI6CAN.sch]
2019-04-25 Replaced MCP2551 with TCAN332DR
    [FSI6CAN.brd, FSI6CAN.sch]
2019-05-02 Major rework using ATmega328p and MCP2515 for v2.0 release
    [FSI6CAN.brd, FSI6CAN.sch]
2019-05-08 Improved designators for assembly
    [FSI6CAN.brd]
2019-05-10 Fixed silkscreen labels for outputs and for MCU orientation
    [FSI6CAN.brd, FSI6CAN.sch]
2019-09-17 Part replacement using SuperHouse libraries
    [FSI6CAN.brd, FSI6CAN.sch]
2019-10-03 Renamed files migrated from FSI6CAN project
    [CHAIRCONTROLMOTORS.brd, CHAIRCONTROLMOTORS.sch]
2019-10-06 Added XTxx external connections
    [CHAIRCONTROLMOTORS.brd, CHAIRCONTROLMOTORS.sch]
2019-10-07 Major schematic replacement to switch to 32U4 processor
    [CHAIRCONTROLMOTORS.brd, CHAIRCONTROLMOTORS.sch]
2019-10-08 Schematic cleanups and start of placement
    [CHAIRCONTROLMOTORS.brd, CHAIRCONTROLMOTORS.sch]
2019-10-09 More routing
    [CHAIRCONTROLMOTORS.brd, CHAIRCONTROLMOTORS.sch]
2019-10-15 Added brake status detection, finished routing
    [CHAIRCONTROLMOTORS.brd, CHAIRCONTROLMOTORS.sch]
2019-10-21 Finished up silkscreen and routing
    [CHAIRCONTROLMOTORS.brd]
2019-10-21 Renamed project files
    [WMC.brd, WMC.sch]
2019-10-21 Major mechanical restructure to mount RoboClaw on top of control board
    [WMC.brd]
2019-10-22 Routing, ERC, DRC for v1.0 release
    [WMC.brd, WMC.sch]
2019-11-14 Added central dead spot to stop chair jittering at rest
    [config.h]
2020-03-18 Changed lock status LEDs to green to indicate chair will move when locks released - green means go
    [WMC.brd, WMC.sch]
2020-07-14 Moved files in preparation for merge
    [WMC.brd, WMC.sch]

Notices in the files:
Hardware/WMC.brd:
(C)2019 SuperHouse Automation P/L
